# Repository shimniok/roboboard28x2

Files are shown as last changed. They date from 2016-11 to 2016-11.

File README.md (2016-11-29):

# roboboard28x2
Robot controller board for PICAXE-28X2.

Built for 5th grade robotics club that I'm leading. It's a low cost "baseboard" for the
PICAXE with built-in USB connector and FTDI chip.

By using an onboard FTDI we save versus the retail cost of FTDI breakout boards which are
also easy to lose.

Breaks out each pin with a corresponding VCC and GND for convenient hookup of sensors and
controllers.

The board has a footprint for a Pololu S10V4F5 step-up/step-down switching regulator
daughterboard (or anything with an equivalent pinout) to provide a steady 5V from 4AA 
batteries for sake of predictability.

Also expects to use a separate motor control board (using the Pololu DRV8835 breakout in
this case but any low voltage motor controller will work).

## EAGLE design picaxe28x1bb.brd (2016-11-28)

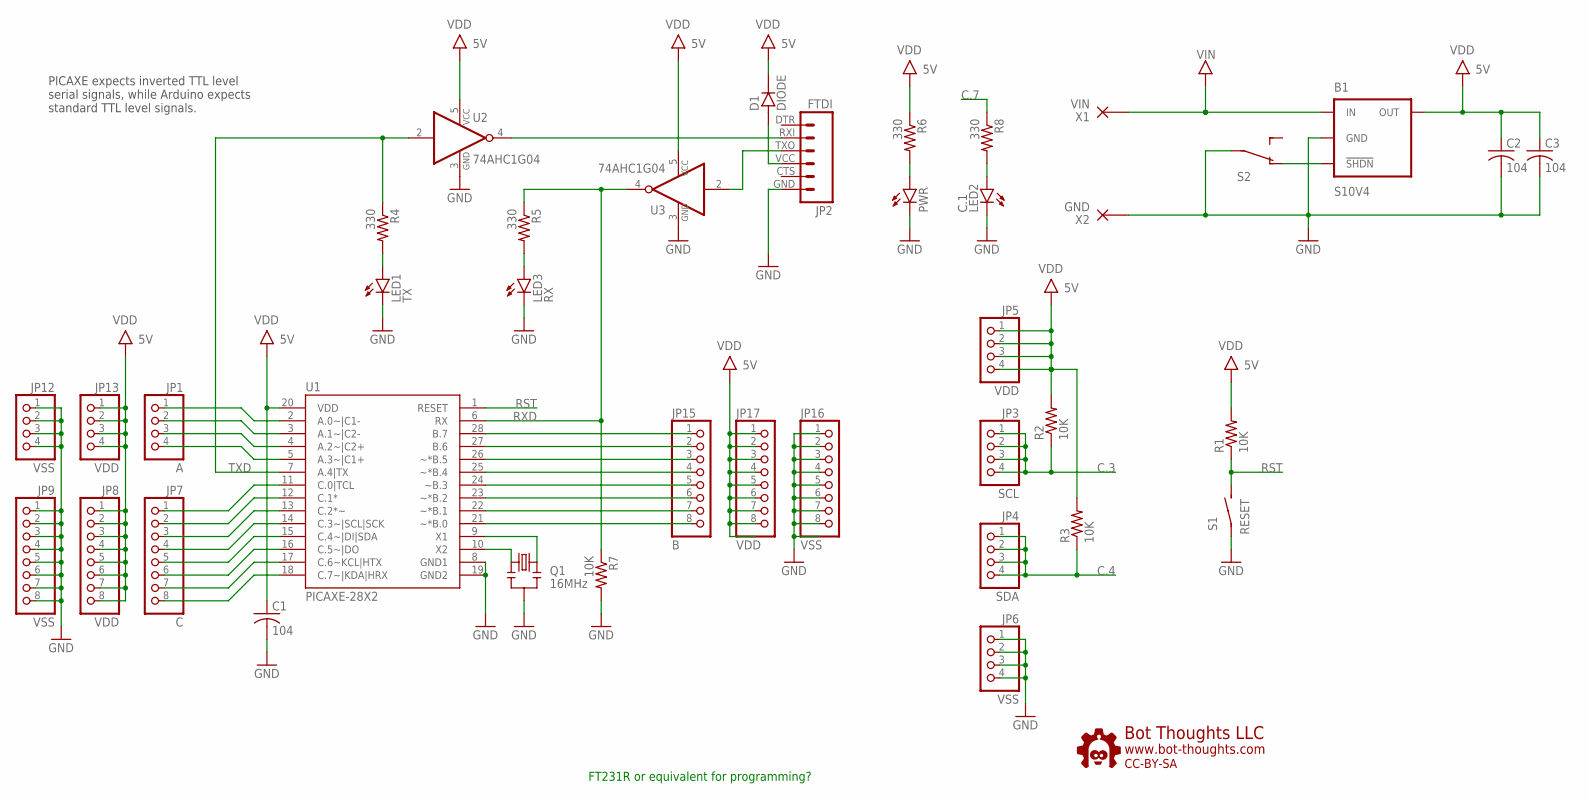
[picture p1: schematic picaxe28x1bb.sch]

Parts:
B1: S10V4; POLOLU-S10V4
C1, C2, C3: 104; C0603
D1: DIODE; SOD123FL
JP1: A; 1X04-S
JP2: FTDI; FTDI_BASIC
JP3: SCL; 1X04-S
JP4: SDA; 1X04-S
JP5, JP13: VDD; 1X04-S
JP6, JP12: VSS; 1X04-S
JP7: C; 1X08-S
JP8, JP17: VDD; 1X08-S
JP9, JP16: VSS; 1X08-S
JP15: B; 1X08-S
LED1: TX; CHIPLED_0805
LED2: C.1; CHIPLED_0805
LED3: RX; CHIPLED_0805
PWR: LEDCHIPLED_0805; CHIPLED_0805
Q1: 16MHz; CSTCE_V_C
R1, R2, R3, R7: 10K; R0603
R4, R5, R6, R8: 330; R0603
S1: RESET; 3X4X2TACT
S2: SPDT_OS102011MAQN1; OS102011MA1Q
U1: PICAXE-28X2; DIL28-3
U2, U3: 74AHC1G04; SOT23-5
U$10: BTLOGO-LOGO-MD; BTLOGOM
X1: VIN; PAD_18GA
X2: GND; PAD_18GA

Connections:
A.0: JP1.1, U1.2 (A.0~|C1-)
A.1: JP1.2, U1.3 (A.1~|C2-)
A.2: JP1.3, U1.4 (A.2~|C2+)
A.3: JP1.4, U1.5 (A.3~|C1+)
B.0: JP15.8, U1.21 (~*B.0)
B.1: JP15.7, U1.22 (~*B.1)
B.2: JP15.6, U1.23 (~*B.2)
B.3: JP15.5, U1.24 (~B.3)
B.4: JP15.4, U1.25 (~*B.4)
B.5: JP15.3, U1.26 (~*B.5)
B.6: JP15.2, U1.27 (B.6)
B.7: JP15.1, U1.28 (B.7)
C.0: JP7.1, U1.11 (C.0|TCL)
C.1: JP7.2, U1.12 (C.1*)
C.2: JP7.3, U1.13 (C.2*~)
C.3: JP3.1, JP3.2, JP3.3, JP3.4, JP7.4, R2.1, U1.14 (C.3~|SCL|SCK)
C.4: JP4.1, JP4.2, JP4.3, JP4.4, JP7.5, R3.1, U1.15 (C.4~|DI|SDA)
C.5: JP7.6, U1.16 (C.5~|DO)
C.6: JP7.7, U1.17 (C.6~KCL|HTX)
C.7: JP7.8, R8.1, U1.18 (C.7~|KDA|HRX)
EN: B1.!SHDN, S2.P$1 (O1)
GND: B1.GND, C1.2, C2.2, C3.2, JP2.GND (6), JP6.1, JP6.2, JP6.3, JP6.4, JP9.1, JP9.2, JP9.3, JP9.4, JP9.5, JP9.6, JP9.7, JP9.8, JP12.1, JP12.2, JP12.3, JP12.4, JP16.1, JP16.2, JP16.3, JP16.4, JP16.5, JP16.6, JP16.7, JP16.8, LED1.C, LED2.C, LED3.C, PWR.C, Q1.GND, R7.2, S1.P$1, S2.P$2, U1.8 (GND1), U1.19 (GND2), U2.3 (GND), U3.3 (GND), X2.P$1
unnamed: LED2.A, R8.2
unnamed: PWR.A, R6.2
unnamed: D1.A, JP2.VCC (4)
unnamed: LED1.A, R4.2
unnamed: LED3.A, R5.2
unnamed: Q1.X2, U1.10 (X2)
unnamed: Q1.X1, U1.9 (X1)
RST: R1.1, S1.P$2 (S), U1.1 (RESET)
RXD: R5.1, R7.1, U1.6 (RX), U3.4 (O)
RXI: JP2.RXI (2), U2.4 (O)
TXD: R4.1, U1.7 (A.4|TX), U2.2 (I)
TXO: JP2.TXO (3), U3.2 (I)
VDD: B1.VOUT (OUT), C1.1, C2.1, C3.1, D1.C, JP5.1, JP5.2, JP5.3, JP5.4, JP8.1, JP8.2, JP8.3, JP8.4, JP8.5, JP8.6, JP8.7, JP8.8, JP13.1, JP13.2, JP13.3, JP13.4, JP17.1, JP17.2, JP17.3, JP17.4, JP17.5, JP17.6, JP17.7, JP17.8, R1.2, R2.2, R3.2, R6.1, U1.20 (VDD), U2.5 (VCC), U3.5 (VCC)
VIN: B1.VIN (IN), X1.P$1

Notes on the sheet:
FT231R or equivalent for programming?
PICAXE expects inverted TTL level serial signals, while Arduino expects standard TTL level signals.

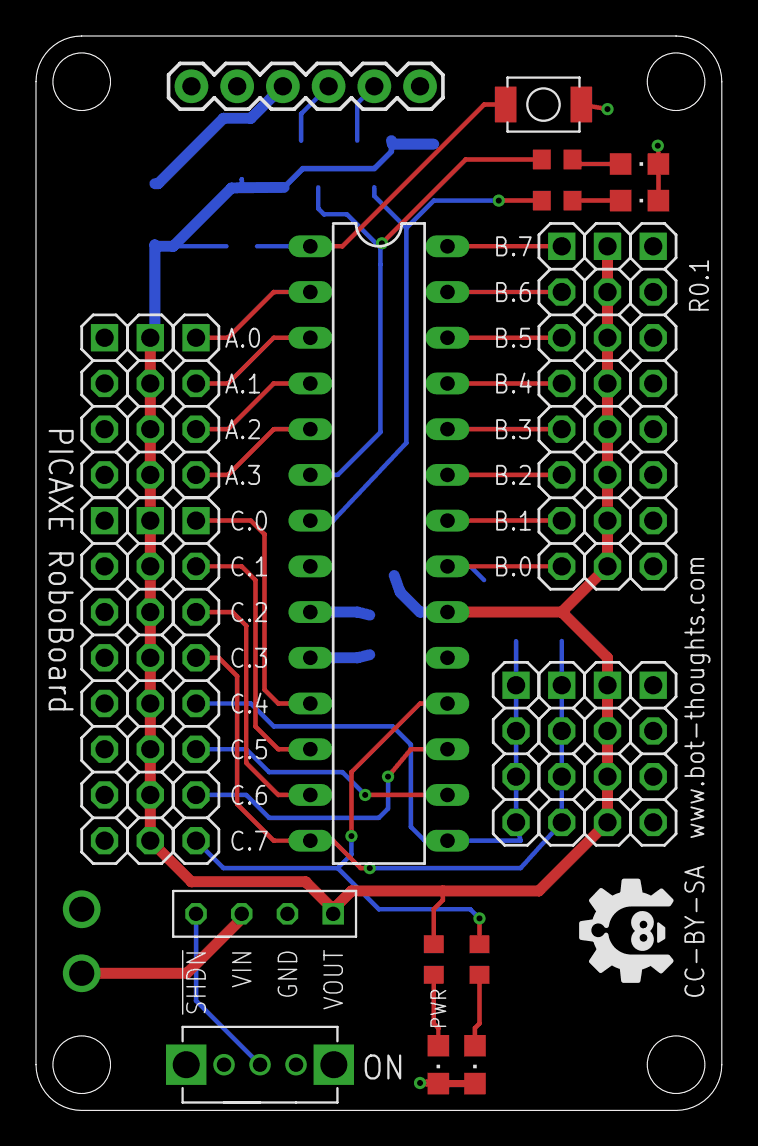
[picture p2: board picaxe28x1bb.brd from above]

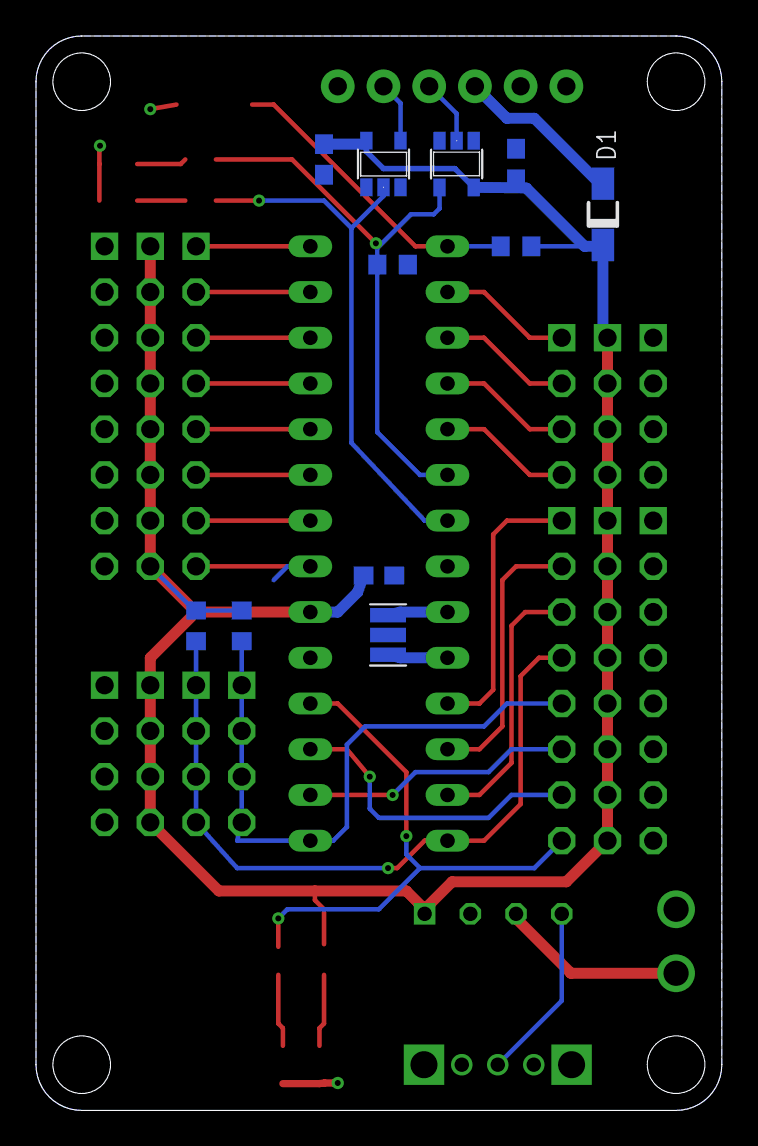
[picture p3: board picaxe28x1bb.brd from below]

Board: 2 copper layers, 38.1 x 59.7 mm, 40 parts (11 on the bottom side), 36 nets.

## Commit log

2016-11-27 initial version
    [picaxe28x1bb.brd, picaxe28x1bb.sch]
2016-11-28 updated layout, leds, inverted serial, etc.
    [picaxe28x1bb.brd, picaxe28x1bb.sch]

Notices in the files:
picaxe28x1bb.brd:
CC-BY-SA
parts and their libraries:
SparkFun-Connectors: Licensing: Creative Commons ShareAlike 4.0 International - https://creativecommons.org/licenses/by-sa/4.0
